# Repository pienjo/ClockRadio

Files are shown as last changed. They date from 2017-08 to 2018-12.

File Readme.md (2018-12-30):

This is just a simple alarm clock.

How to use
==========

## Main display

A short press on the mode button rotates between the following modes:

  * Time. The first 2 columns of the LED display are used for a Day-of-week indicator; monday is at the first row.
  * Date
  * Alarm 1.  
  * Alarm 2. 
  * One-time alarm

A long press on the mode button will edit whatever is being displayed (time,
alarm 1, alarm 2, or one-time alarm). Performing a long press while the
date is being shown will edit the time drift compensation. The display will
return to ''Time'' when no buttons are pressed.

## Display brightness

The display has separate brightness settings for day and night. Transition 
from day to night occurs roughly around sunrise (Assuming a northern 
lattitude of aroudn 51 degrees). 

Brightness can be changed using the ''increase'' and ''decrease'' buttons while the 
display is showing the time.

## Daylight saving time

The clock will automatically apply daylight saving time, based on the current (2019) 
EU rules (which are bound to change again, oh well)

## Editing

A short press on the mode button will advance to the next digit/number. Use 
the increment/decrement buttons to change digits/numbers. A long press
on the mode button will abort the edit.

## Radio

Pressing the on/off button will toggle the radio. When the radio is active,
the "Time" page will show the tuned frequency instead. When the radio is on,
the "Increase" and "Decrease" can be used for tuning. A short press on either
button will do a manual tune, a long press will perform an automatic seek for
the next channel.

To change the volume of the radio, hold down the on/off button and use the
increase/decrease buttons for volume control.

## Alarm

There are 2 regular alarms. They can sound on weekdays, on weekends, or both. 
They can be edited by doing a long-press on the mode button while the relevant
alarm is being displayed.

To disable or enable an alarm, press the ''on/off'' button while the alarm is
being displayed. Press the ''increment'' button to silence only the upcoming
invocation of the alarm. I added this because I often wake up before the
alarm is set to sound; in these cases I want to disable the alarm for today, 
but it should still arm itself for tomorrow without me having to remember
doing so...

Alarms can either turn on the radio, or turn on the beeper. While an alarm is
active, any button can be used to disable the alarm (the regular function of
the buttons is disabled while an alarm is active). When an alarm is scheduled
to go off while the previous alarm is still active, the first alarm is 
automatically silenced. (for example: my first alarm turns on the radio at
6:55 so I can listen to the news. If I'm not out of bed by 7:10, the second
alarm will sound the beeper).

Alarms will automatically be disabled after a certain timeout (1 hour for
radio alarms, 4 minutes for beeper alarms).

There is also a one-time alarm, for those times where you need to wakeup
at a non-standard hour. It behaves the same as the normal alarms, but doesn't
re-arm itself.

## sleep/nap

There is a sleep- or naptimer, sharing a single button. When the radio is
turned on while the sleep/nap button is pressed, the sleep function activates.
Press the button repeatedly to change the desired sleep interval. The radio
will turn off after this time.

If the radio was turned off when the sleep/nap button was pressed, the nap
function activates. It will sound the beeper alarm once the nap timer has 
expred. Press the sleep/nap button repeatedly to change the desired nap 
interval.

Both sleep and nap timers have a '':00'' interval - Selecting this interval
will disable the sleep/nap timer.

Hardware
========

Unfortunately, I lost the schematics for this clock. It was kind of cobbled
together at the spot. I'll include an overview, which should be enough to 
recreate a suitable schematic.

## Buttons

There are 5 switches, which pull down to GND:
 
  * **mode** (''BUTTON_1'', connected to PD0)
  * **on/off** (''BUTTON_2'', connected to PD1) 
  * **decrease** (''BUTTON_3'', connected to PD3)
  * **increase** (''BUTTON_4'', connected to PD4)
  * **sleep/nap** (''BUTTON_5'', connected to PD5)

There is **no** button connected to PD2 (ex0). Instead, it is connected to the
clock output of the DS1307. This will generate ''CLOCK_UPDATE'' events.

## Display 

The display consists of 4 MAX7219 modules from AliExpress. They came with an
8x8 LED matrix, and are connected in cascade (DOUT connected to DIN of the next
module. SCK is shared among all modules). 

They are configured over SPI, and use the hardware SPI module of the AVR:

  * MOSI (PB3 of the AVR) is connected to DIN of the first module.
  * SCK (PB5 of the AVR) is connected to CLK of the first module.
  * PB2 is connected to LOAD(/CS) of the first module.

I replaced the 8x8 matrix of the last module with a 4x7 segment display
plus some status LEDs on an adapter board. See the "schematics" in 
Hardware/display ) Note that the 4x7 segment that I happened to find in my
parts bin was common anode rather than common cathode!

## FM Radio

The clock uses an SI4702 radio module. **This module must be supplied with
3.3V**. I used an XC6206 low-dropout regulator.

The module is configured over I2C, using the hardware I2C module (SDA at PC4,
SCL at PC5). These need to be level-shifted because of difference in supply
voltage - I used a standard BSS138 based level shifter. See 
Hardware/levelshifter .

In addition, the reset line of the SI4702 module is connected to PC3. It 
doesn't need a level shifter; the AVR will only pull this low during the
power-up of the FM radio.

The outputs of the SI4702 need to be decoupled using a suitably large 
capacitor (I think I used a 10 uF electrolytic) because of different biasing.

## Beeper 

PC1 is used to generate a crude beeper. It is connected to the input of the
audio amplifier, using a potentiometer (for volume control) and a small
decoupling capacitor.

## Audio amplifier

I used a cheap amplifier module from AliExpress (LM386-based), connected to
4 small (29mm) speakers, .25W @ 8 Ohm, connected in two parallel chains of
2 (for a total impedance of 8 Ohm).

Since this amplifier turned out to be rather noisy, I added a PNP transistor
to its supply line, so it can be turned off if the radio and beeper are 
quiet. This transistor is controlled by PC2.

Building
========

You need to have the following installed:

  * A recent version of gcc-avr 
  * A recent version of avr-libc
  * avrdude for programming. The TX and RX lines are in use, so it's
    probably best to use an ISP programmer.
  * lua (5.1 or 5.2) to generate the bitmap- and font code.

To run the unittests in tests, you'll also need simavr plus its headers.

Case
====

I posted the case I made for this alarm clock to Thingiverse, see 

https://www.thingiverse.com/thing:3313125

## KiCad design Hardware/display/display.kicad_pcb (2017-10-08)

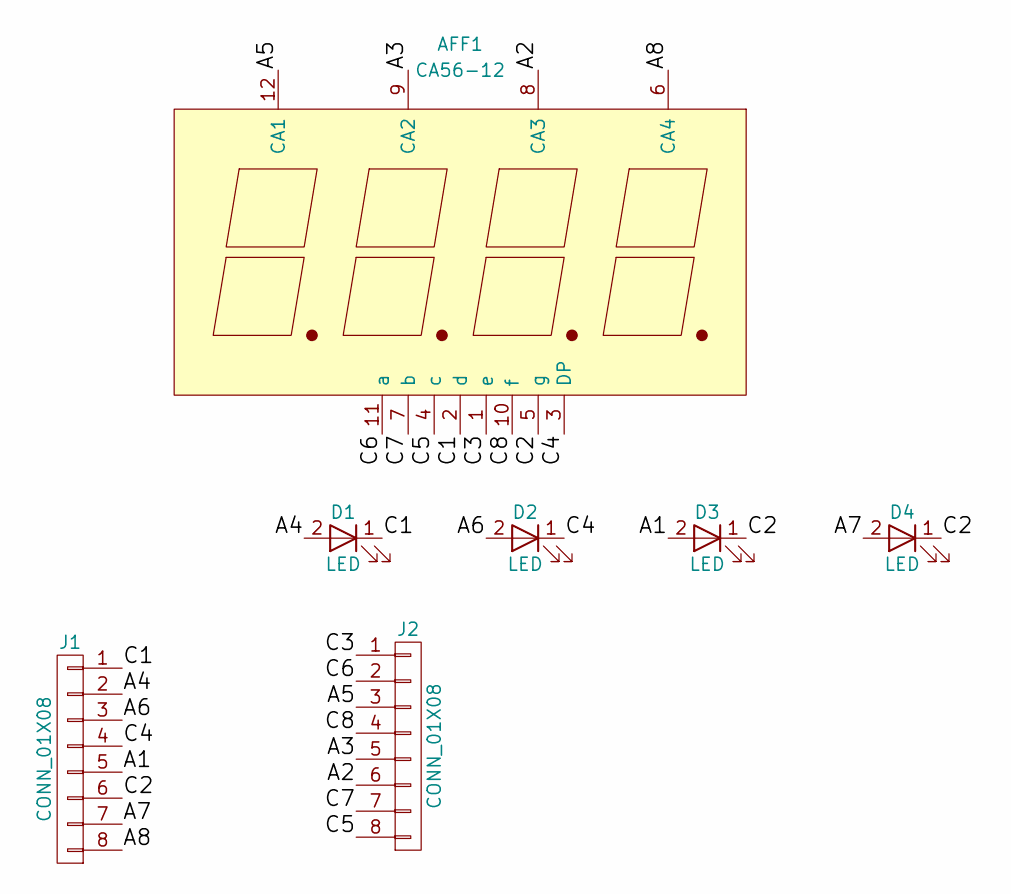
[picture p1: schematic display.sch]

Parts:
AFF1: CA56-12; SMA413064
D1, D2, D3, D4: LED; LED_D5.0mm
J1, J2: CONN_01X08; Pin_Header_Straight_1x08_Pitch2.54mm

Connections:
/A1: D3.2 (A), J1.5
/A2: AFF1.8 (CA3), J2.6
/A3: AFF1.9 (CA2), J2.5
/A4: D1.2 (A), J1.2
/A5: AFF1.12 (CA1), J2.3
/A6: D2.2 (A), J1.3
/A7: D4.2 (A), J1.7
/A8: AFF1.6 (CA4), J1.8
/C1: AFF1.2 (d), D1.1 (K), J1.1
/C2: AFF1.5 (g), D3.1 (K), D4.1 (K), J1.6
/C3: AFF1.1 (e), J2.1
/C4: AFF1.3 (DP), D2.1 (K), J1.4
/C5: AFF1.4 (c), J2.8
/C6: AFF1.11 (a), J2.2
/C7: AFF1.7 (b), J2.7
/C8: AFF1.10 (f), J2.4

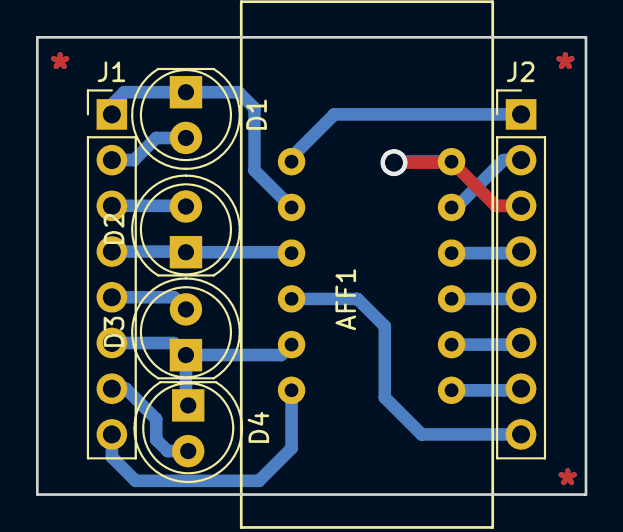
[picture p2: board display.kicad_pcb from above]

Board: 2 copper layers, 30.5 x 25.4 mm, 7 parts (0 on the bottom side), 16 nets.

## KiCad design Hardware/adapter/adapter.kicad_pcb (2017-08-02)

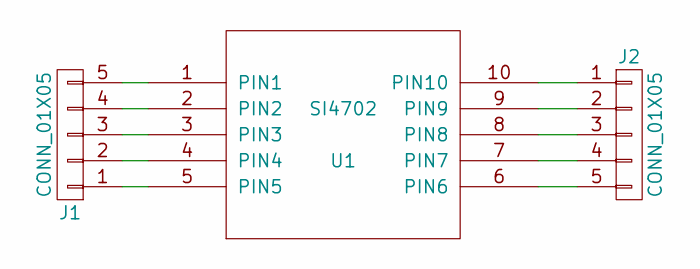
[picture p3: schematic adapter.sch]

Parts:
J1, J2: CONN_01X05; Pin_Header_Straight_1x05_Pitch2.54mm
U1: SI4702; mvb_SI4702

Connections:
unnamed: J1.1, U1.5 (PIN5)
unnamed: J1.2, U1.4 (PIN4)
unnamed: J1.3, U1.3 (PIN3)
unnamed: J1.4, U1.2 (PIN2)
unnamed: J1.5, U1.1 (PIN1)
unnamed: J2.1, U1.10 (PIN10)
unnamed: J2.2, U1.9 (PIN9)
unnamed: J2.3, U1.8 (PIN8)
unnamed: J2.4, U1.7 (PIN7)
unnamed: J2.5, U1.6 (PIN6)

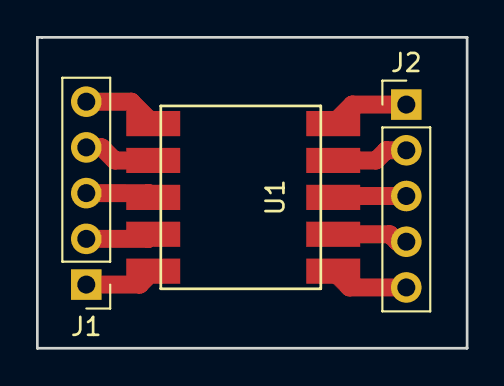
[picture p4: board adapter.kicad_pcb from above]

Board: 2 copper layers, 23.9 x 17.3 mm, 3 parts (0 on the bottom side), 10 nets.

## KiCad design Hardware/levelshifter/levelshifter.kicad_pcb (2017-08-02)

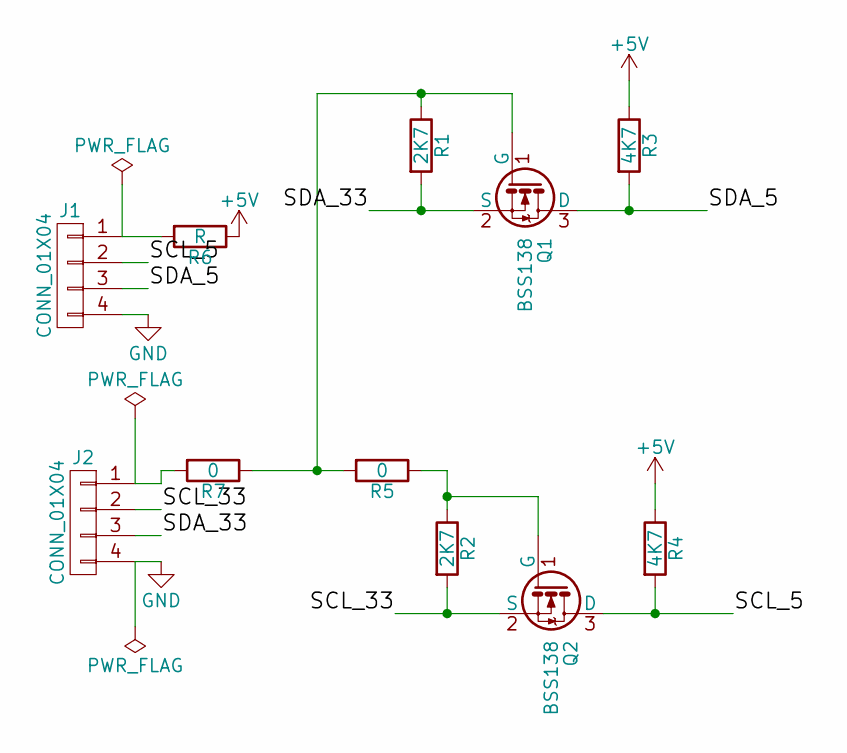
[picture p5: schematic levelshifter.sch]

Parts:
J1, J2: CONN_01X04; Pin_Header_Straight_1x04_Pitch2.54mm
Q1, Q2: BSS138; SOT-23_Handsoldering
R1, R2: 2K7; R_0603_HandSoldering
R3, R4: 4K7; R_0603_HandSoldering
R5: 0; R_Axial_DIN0204_L3.6mm_D1.6mm_P5.08mm_Horizontal
R6: R; R_Axial_DIN0204_L3.6mm_D1.6mm_P5.08mm_Horizontal
R7: 0; R_Axial_DIN0204_L3.6mm_D1.6mm_P7.62mm_Horizontal

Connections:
+5V: R3.1, R4.1, R6.1
/SCL_5: J1.2, Q2.3 (D), R4.2
/SCL_33: J2.2, Q2.2 (S), R2.2
/SDA_5: J1.3, Q1.3 (D), R3.2
/SDA_33: J2.3, Q1.2 (S), R1.2
GND: J1.4, J2.4
unnamed: J1.1, R6.2
unnamed: J2.1, R7.2
unnamed: Q1.1 (G), R1.1, R5.2, R7.1
unnamed: Q2.1 (G), R2.1, R5.1

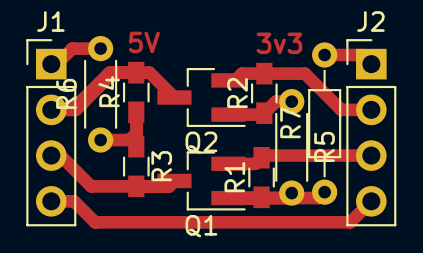
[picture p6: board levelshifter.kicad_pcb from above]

Board: 2 copper layers, 11 parts (0 on the bottom side), 10 nets.

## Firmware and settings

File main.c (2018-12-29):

/*
Copyright 2018, Martijn van Buul <martijn.van.buul@gmail.com>

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
THE SOFTWARE IS PROVIDED "AS IS" AND THE AUTHOR DISCLAIMS ALL WARRANTIES WITH
REGARD TO THIS SOFTWARE INCLUDING ALL IMPLIED WARRANTIES OF MERCHANTABILITY AND
FITNESS. IN NO EVENT SHALL THE AUTHOR BE LIABLE FOR ANY SPECIAL, DIRECT,
INDIRECT, OR CONSEQUENTIAL DAMAGES OR ANY DAMAGES WHATSOEVER RESULTING FROM
LOSS OF USE, DATA OR PROFITS, WHETHER IN AN ACTION OF CONTRACT, NEGLIGENCE OR
OTHER TORTIOUS ACTION, ARISING OUT OF OR IN CONNECTION WITH THE USE OR
PERFORMANCE OF THIS SOFTWARE.
*/
#include <avr/io.h>
#include <util/delay.h>
#include "Renderer.h"
#include "Panels.h"
#include "DateTime.h"
#include "events.h"
#include "longpress.h"
#include "DS1307.h"
#include "SI4702.h"
#include "settings.h"
#include "Timefuncs.h"
#include "BCDFuncs.h"

#include "i2c.h"

#include <avr/interrupt.h>
#include <avr/sleep.h>
#include <avr/wdt.h>
#include <util/atomic.h>

struct DateTime TheDateTime;
struct DateTime ThePreviousDateTime;

uint8_t TheSleepTime = 0;
uint8_t TheNapTime = 0;


#define BEEP_MARK             3
#define BEEP_SPACE           4
#define BEEP_COUNT           4
#define BEEP_ON_PERIOD       (BEEP_COUNT * (BEEP_MARK + BEEP_SPACE))
#define BEEP_PAUSE             BEEP_ON_PERIOD
#define BEEP_TOTALPERIOD     (BEEP_PAUSE + BEEP_ON_PERIOD)

#define SHOW_ALARM_TIMEOUT   15
#define TIME_ADJUST_TIMEOUT 15

#define ALARM_BEEP_TIMEOUT   4
#define ALARM_RADIO_TIMEOUT  60
#define INITIAL_SLEEPTIME    15
#define INITIAL_NAPTIME      INITIAL_SLEEPTIME

uint8_t beepState = 0;

_Bool radioIsOn = 0;
_Bool beepIsOn = 0;

enum clockMode
{
  modeShowTime,
  modeShowDate,
  modeShowRadio,
  modeShowRadio_Volume,
  modeShowAlarm1,
  modeShowAlarm2,
  modeShowOnetimeAlarm,
  modeAlarmFiring_beep,
  modeAlarmFiring_radio,
  modeAdjustYearTens,
  modeAdjustYearOnes,
  modeAdjustMonth,
  modeAdjustDayTens,
  modeAdjustDayOnes,
  modeAdjustHoursTens,
  modeAdjustHoursOnes,
  modeAdjustMinsTens,
  modeAdjustMinsOnes,
  modeAdjustHoursTens_Alarm,
  modeAdjustHoursOnes_Alarm,
  modeAdjustMinsTens_Alarm,
  modeAdjustMinsOnes_Alarm,
  modeAdjustDays_Alarm,
  modeAdjustType_Alarm,
  modeAdjustSleep,
  modeAdjustNap,
  modeAdjustTimeAdjust
} ;

volatile uint16_t event ;

uint8_t timer2_scaler = 2;

ISR (TIMER2_OVF_vect)
{
  // Crude button debouncer
  static uint8_t buttonDebounce[4] = { 0 };

  // First 3 array members are the debounce queue
  // Last array member is the reported button state
  
  // Add new data
  buttonDebounce[timer2_scaler] = PIND;
  
  // Handle beeping here, so timing is strict
  if (beepIsOn)
  {
    beepState = beepState + 1;
    
    if (beepState >= BEEP_TOTALPERIOD)
      beepState = 0;
    
    if (beepState < BEEP_ON_PERIOD)
    {
      uint8_t remainder = beepState;
      while(remainder >= (BEEP_MARK + BEEP_SPACE))
        remainder -= BEEP_MARK + BEEP_SPACE;
        
      if (remainder == 0)
      {
        // Turn on beeper
        TCCR0B = _BV(CS01) | _BV(CS00);
      }
      else if (remainder == BEEP_MARK)
      {
        // Turn off beeper
        TCCR0B = 0;
        PORTC &= ~(_BV(PORTC1));
      }
    }
  }
  
  uint8_t buttonsToReport = ~((buttonDebounce[0] ^ buttonDebounce[1]) | (buttonDebounce[1] ^ buttonDebounce[2]));
  // Now holds all buttons whose state has been stable over the last 3 scans (all values equal)

  // Only report buttons that haven't been reported yet.
  buttonsToReport &= (buttonDebounce[timer2_scaler] ^ buttonDebounce[3]);
 
  if (buttonsToReport)
  {
    // Mark as handled
    buttonDebounce[3] =( buttonDebounce[3] & (~buttonsToReport) ) | (buttonsToReport & buttonDebounce[timer2_scaler]);
  
    uint8_t pressedButtons = buttonsToReport & ~(buttonDebounce[timer2_scaler]);
    uint8_t releasedButtons = buttonsToReport & (buttonDebounce[timer2_scaler]);
    
    // Report
    event |= (uint16_t) pressedButtons | ((uint16_t)releasedButtons << 8);
  }

  if (timer2_scaler == 0)
  {
    event |= CLOCK_TICK; // results in ~48 ms per call
    timer2_scaler = 2;
  }
  else
  {
    timer2_scaler--;
  }
}

ISR (TIMER0_COMPA_vect)
{
  PINC = _BV(PORTC1); // Toggle output
}

static inline _Bool IsPastAlarmTime(const struct AlarmSetting *alarm, const struct DateTime *timestamp)
{
  return (timestamp->hour > alarm->hour) || (timestamp->hour == alarm->hour && timestamp->min >= alarm->min);
}

enum enumAlarmScheduleState {
  NOT_SCHEDULED = LED_OFF,          // Alarm is not scheduled for the next 24 hours
  SCHEDULED = LED_ON,                 // Alarm is scheduled
  SUSPENDED = LED_BLINK_SHORT,      // Alarm would've been scheduled, but the next invocation is suspended
};

enum enumAlarmScheduleState IsAlarmScheduled(struct AlarmSetting *alarm)
{
  if ((alarm->flags & ALARM_ACTIVE) == 0)
    return NOT_SCHEDULED;
  
  uint8_t dayBits = 0xff; // bit 0 = monday, bit 1 = tuesday ... bit 7 is monday again, to handle wraparound.
  
  switch (alarm->flags & ALARM_DAY_BITS)
  {
    case ALARM_DAY_WEEK:
      dayBits = 0x9f; // Trigger on mon-fri
      break;
    case ALARM_DAY_WEEKEND:
      dayBits = 0x60; // Trigger on sat-sun
  }
  
  // See if next alarm time is today or tomorrow.
  uint8_t nextAlarmDay; // 0-based
  
  if (IsPastAlarmTime(alarm, &TheDateTime))
  {
    // Alarm will trigger tomorrow.
    nextAlarmDay = TheDateTime.wday;
  }
  else
  {
    // Alarm will trigger today
    nextAlarmDay = TheDateTime.wday - 1; // 0-6
  }
    
  // Check if day matches
  if (! ( dayBits & (1 << nextAlarmDay)))
    return NOT_SCHEDULED;
    
  if ((alarm->flags & ALARM_SUSPENDED) == 0)
    return SCHEDULED;
  else
    return SUSPENDED;
}

void BeepOff()
{
  TCCR0B = 0; // Stop timer
  beepIsOn = 0;
  
  // Force beeper output low
  PORTC &= ~ _BV(PORTC1);
  
  // Amplifier control is active low
  PORTC = PORTC | _BV(PORTC2); 
}

void RadioOff()
{
  // Amplifier control is active low
  PORTC = PORTC | _BV(PORTC2);
  
  SI4702_PowerOff();
  radioIsOn = 0;
  TheSleepTime = 0;
}

void BeepOn()
{
  if (radioIsOn)
  {
    RadioOff();
  }
  
  beepIsOn = 1;
  beepState = BEEP_ON_PERIOD;

  // Amplifier control is active low
  PORTC = PORTC & ~( _BV(PORTC2)); 
}

_Bool RadioOn()
{
  if (radioIsOn)
    return 1; // Already on.
    
  if (beepIsOn)
  {
    BeepOff();
  }
  
  if (!SI4702_PowerOn())
  {
    return 0; // Failed to start the radio
  }
  
  SI4702_SetFrequency(TheGlobalSettings.radio.frequency);
  SI4702_SetVolume(TheGlobalSettings.radio.volume);
  
  Poll_SI4702();
  // Amplifier control is active low
  
  PORTC = PORTC & ~( _BV(PORTC2)); 
  radioIsOn = 1;  
  return 1;
}

uint8_t alarm1Timeout = 0; // minutes
uint8_t alarm2Timeout = 0; // minutes
uint8_t onetimeAlarmTimeout = 0; // minutes
uint8_t napTimeout = 0; // minutes

enum enumAlarmScheduleState alarm1Scheduled = NOT_SCHEDULED, alarm2Scheduled = NOT_SCHEDULED, onetimeAlarmScheduled = NOT_SCHEDULED;

void SilenceAlarm(struct AlarmSetting *alarm)
{
  if (alarm->flags & ALARM_TYPE_RADIO)
  {
    RadioOff();
  }
  else
  {
    BeepOff();
  }
}
  
_Bool AlarmTriggered(struct AlarmSetting *alarm)
{
  if (IsPastAlarmTime(alarm, &ThePreviousDateTime))
    return 0; // already triggered

  if (!IsPastAlarmTime(alarm, &TheDateTime) && ThePreviousDateTime.hour <= TheDateTime.hour)
    return 0; // Alarm not yet triggered, and no roll-over

  if ((alarm->flags & ALARM_DAY_NEVER) == ALARM_DAY_NEVER)
  {
    // Turn off alarm on one-time alarms
    alarm->flags &= ~ALARM_ACTIVE;
  }
  
  return 1;
}

void HandleCycleTime(uint8_t *time)
{
  uint8_t remainder = *time % 15;
  
  *time += (15 - remainder);
  if (*time > 150)
    *time = 0;
}

struct deviceState
{
  uint8_t modeTimeout;
  int8_t  timeAdjustRemainder;
  _Bool   timeAdjustApplied;
  enum clockMode deviceMode;

} TheDeviceState;

void SilenceAlarms()
{
  if (alarm1Timeout)
  {
    alarm1Timeout--;
    if (!alarm1Timeout)
      SilenceAlarm(&TheGlobalSettings.alarm1);
  }
  
  if (alarm2Timeout)
  {
    alarm2Timeout--;
    if (!alarm2Timeout)
      SilenceAlarm(&TheGlobalSettings.alarm2);
  }
  
  if (onetimeAlarmTimeout)
  {
    onetimeAlarmTimeout--;
    if (!onetimeAlarmTimeout)
      SilenceAlarm(&TheGlobalSettings.onetime_alarm);
  }
  
  if (TheSleepTime && TheDeviceState.deviceMode != modeAdjustSleep)
  {
    TheSleepTime--;
    if (TheSleepTime == 0)
    {
      RadioOff();
      if (!TheDeviceState.modeTimeout)
        TheDeviceState.modeTimeout = 1;
    }
  }
  
  if (napTimeout)
  {
    napTimeout--;
    if (!napTimeout)
    {
      BeepOff();
    }
  }
}

enum clockMode ActivateAlarms()
{
  enum clockMode newDeviceMode = TheDeviceState.deviceMode;

  if (TheNapTime && TheDeviceState.deviceMode != modeAdjustNap)
  {
    TheNapTime--;
    if (TheNapTime == 0)
    {
      BeepOn();
      alarm1Timeout = 0;
      alarm2Timeout = 0;
      TheSleepTime = 0;
      napTimeout = ALARM_BEEP_TIMEOUT;
      newDeviceMode = modeAlarmFiring_beep;
    }
  }
  
  // See if alarms must fire.
  
  switch(alarm1Scheduled)
  {
    case NOT_SCHEDULED:
      break;
    case SCHEDULED:
      if (AlarmTriggered(&TheGlobalSettings.alarm1))
      {
        napTimeout = 0;
        alarm2Timeout = 0;
        onetimeAlarmTimeout = 0;
        TheSleepTime = 0;
        
        if ((TheGlobalSettings.alarm1.flags & ALARM_TYPE_RADIO) && RadioOn())
        {
          // Radio alarm, and radio could be started
          
          alarm1Timeout = ALARM_RADIO_TIMEOUT;
          newDeviceMode = modeAlarmFiring_radio;
        }
        else
        {
          // Beep alarm, or failed to start radio
          BeepOn();
          alarm1Timeout = ALARM_BEEP_TIMEOUT;
          newDeviceMode = modeAlarmFiring_beep;
        }
      }
      break;
    case SUSPENDED:
      if (AlarmTriggered(&TheGlobalSettings.alarm1))
      {
        // Remove suspend state
        TheGlobalSettings.alarm1.flags &= ~(ALARM_SUSPENDED);
      }
      break;
  }
  
  switch(alarm2Scheduled)
  {
    case NOT_SCHEDULED:
      break;
    case SCHEDULED:
      if (AlarmTriggered(&TheGlobalSettings.alarm2))
      {
        napTimeout = 0;
        alarm1Timeout = 0;
        onetimeAlarmTimeout = 0;
        TheSleepTime = 0;
        
        if ((TheGlobalSettings.alarm2.flags & ALARM_TYPE_RADIO) && RadioOn())
        {
          // Radio alarm, and radio could be started
          
          alarm2Timeout = ALARM_RADIO_TIMEOUT;
          newDeviceMode = modeAlarmFiring_radio;
        }
        else
        {
          // Beep alarm, or failed to start radio
          BeepOn();
          alarm2Timeout = ALARM_BEEP_TIMEOUT;
          newDeviceMode = modeAlarmFiring_beep;
        }
      }
      break;
    case SUSPENDED:
      if (AlarmTriggered(&TheGlobalSettings.alarm2))
      {
        // Remove suspend state
        TheGlobalSettings.alarm2.flags &= ~(ALARM_SUSPENDED);
      }
      break;
  }
  
  if(onetimeAlarmScheduled == SCHEDULED && AlarmTriggered(&TheGlobalSettings.onetime_alarm))
  {
    napTimeout = 0;
    alarm1Timeout = 0;
    alarm2Timeout = 0;
    TheSleepTime = 0;
    
    if ((TheGlobalSettings.onetime_alarm.flags & ALARM_TYPE_RADIO) && RadioOn())
    {
      // Radio alarm, and radio could be started
      
      onetimeAlarmTimeout = ALARM_RADIO_TIMEOUT;
      newDeviceMode = modeAlarmFiring_radio;
    }
    else
    {
      // Beep alarm, or failed to start radio
      BeepOn();
      onetimeAlarmTimeout = ALARM_BEEP_TIMEOUT;
      newDeviceMode = modeAlarmFiring_beep;
    }
  }

  return newDeviceMode;
}

void ApplyTimeAdjust()
{
  int8_t adjust = 0;

  TheDeviceState.timeAdjustRemainder += TheGlobalSettings.time_adjust;

  if (TheDeviceState.timeAdjustRemainder >= 10)
  {
    while(TheDeviceState.timeAdjustRemainder >= 10)
    {
      ++adjust;
      TheDeviceState.timeAdjustRemainder -= 10;
    }

    if (adjust >= 10)
      adjust += 6;

    TheDateTime.sec = BCDAdd(TheDateTime.sec, adjust);
    Write_DS1307_DateTime();
  }
  else if (TheDeviceState.timeAdjustRemainder <= -10)
  {
    while(TheDeviceState.timeAdjustRemainder <= -10)
    {
      ++adjust;
      TheDeviceState.timeAdjustRemainder += 10;
    }

    if (adjust >= 10)
      adjust += 6;

    TheDateTime.sec = BCDSub(TheDateTime.sec, adjust);
    Write_DS1307_DateTime();
  }
}

int main(void)
{
  // Setup watchdog
  wdt_enable(WDTO_4S);
  
  // Enable output on PORT C2 (amplifier control) and C1 (beeper)
  DDRC |= _BV(PORTC2) | _BV(PORTC1);
  // Amplifier control is active low
  PORTC = PORTC | _BV(PORTC2);
  
  wdt_reset();
  
  InitializePanels(4);
  
  Init_I2C();
  Init_DS1307();
  Init_SI4702();
  Renderer_Init();
  
  // Read radio defaults
  if (!ReadGlobalSettings())
  {
    // settings are lost, initialize
    TheGlobalSettings.radio.frequency = 875; // start of band
    TheGlobalSettings.radio.volume = 26;
    
    TheGlobalSettings.alarm1.flags = ALARM_TYPE_RADIO | ALARM_DAY_WEEK; // Disabled, Repeat on weekdays, radio
    TheGlobalSettings.alarm1.hour = 7;
    TheGlobalSettings.alarm1.min = 0;
    
    TheGlobalSettings.alarm2.flags = ALARM_DAY_WEEKEND; // Disabled, repeat on weekend, beeper
    TheGlobalSettings.alarm2.hour = 9;
    TheGlobalSettings.alarm2.min = 0x15; 
    
    TheGlobalSettings.onetime_alarm.flags = ALARM_DAY_NEVER; // Never repeat, disabled
    TheGlobalSettings.onetime_alarm.hour = 6;
    TheGlobalSettings.onetime_alarm.min = 0x45;
    
    TheGlobalSettings.brightness = 13;
    TheGlobalSettings.brightness_night = 3;
    TheGlobalSettings.time_adjust = 0; 
    WriteGlobalSettings();
  }

  SetBrightness(GetActiveBrightness(&TheDateTime));
  
  // Set port D to input, enable pull-up on portD except for PortD2 (ext0)

  DDRD = 0;
  PORTD = ~(_BV(PORTD2));

  TIMSK2 = _BV(TOIE2); // Enable overflow interrupt, will trigger every 16 ms
  
  // Setup timer 2: /1024 prescaler, 
  TCCR2B = _BV(CS22) | _BV(CS21) | _BV(CS20); 

  // Setup beeper timer.
  TCCR0A = _BV(WGM01); // CTC mode.  
  // Target frequency: 1600 Hz, two interrupts per cycle, or 5000 clock ticks.
  OCR0A = 78; // To be used with a /64 clock scaler
  TIMSK0 = _BV(OCIE0A); // Enable output match interrupt
  
  uint8_t secMode = SECONDARY_MODE_SEC;
  uint8_t mainMode = MAIN_MODE_TIME;

  TheDeviceState.deviceMode = modeShowTime;
  TheDeviceState.modeTimeout = 0;
  TheDeviceState.timeAdjustApplied = true;
  TheDeviceState.timeAdjustRemainder = false;

  uint8_t *editDigit = 0;
  uint8_t editMode = 0;
  uint8_t editMaxValue = 0x99;
  
  uint8_t writeSettingTimeout = 0; // seconds
  
  _Bool timePollAllowed = 1;
  
  sei(); // Enable interrupts. This will immediately trigger a port change interrupt; sink these events.
  
  struct AlarmSetting alarmBeingModified;
  enum clockMode alarmAdjustReturnMode = 0;
  
  uint16_t clockEvents = 0;
  uint16_t buttonEvents = 0;
  struct longPressResult longPressEvent;
  
  longPressEvent.shortPress = 0;
  longPressEvent.longPress = 0;
  longPressEvent.repPress = 0;
  
  while (1)
  {
    
    wdt_reset();
  
    _Bool updateScreen = 0;
    uint16_t acceptedEvents = 0;
    ATOMIC_BLOCK(ATOMIC_FORCEON)
    {
      acceptedEvents = event;
      event = 0;
    }
    
    GetLongPress(acceptedEvents, &longPressEvent);
    clockEvents = (acceptedEvents & (CLOCK_UPDATE | CLOCK_TICK)) ;
    buttonEvents |= (acceptedEvents & ~(CLOCK_UPDATE | CLOCK_TICK));
      
    enum clockMode newDeviceMode = TheDeviceState.deviceMode;

    if (clockEvents & CLOCK_UPDATE)
    {
      if (writeSettingTimeout)
      {
        --writeSettingTimeout;
        if (writeSettingTimeout == 0)
        {
          WriteGlobalSettings();
        }
      }
      
      if (TheDeviceState.modeTimeout && --TheDeviceState.modeTimeout == 0)
      {
         newDeviceMode = (radioIsOn?modeShowRadio : modeShowTime) ;
      }
    
      if (timePollAllowed)
      {
        Read_DS1307_DateTime();
        
        updateScreen = 1;

        if (!TheDeviceState.timeAdjustApplied && TheDateTime.sec >= 30)
        {
          ApplyTimeAdjust();
          TheDeviceState.timeAdjustApplied = true;
        }        

        if (ThePreviousDateTime.sec > TheDateTime.sec)
        {
          // Second rollover.

          if (ThePreviousDateTime.min > TheDateTime.min && TheDateTime.hour == 0)
          {
            // Day rollover. Check for time drift at the 30 second mark.  
            TheDeviceState.timeAdjustApplied = false;
          }

          // See if alarms must timeout
          SilenceAlarms();

          newDeviceMode = ActivateAlarms();
          
          SetBrightness(GetActiveBrightness(&TheDateTime));
        }
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

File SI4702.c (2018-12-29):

/*
Copyright 2018, Martijn van Buul <martijn.van.buul@gmail.com>

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
THE SOFTWARE IS PROVIDED "AS IS" AND THE AUTHOR DISCLAIMS ALL WARRANTIES WITH
REGARD TO THIS SOFTWARE INCLUDING ALL IMPLIED WARRANTIES OF MERCHANTABILITY AND
FITNESS. IN NO EVENT SHALL THE AUTHOR BE LIABLE FOR ANY SPECIAL, DIRECT,
INDIRECT, OR CONSEQUENTIAL DAMAGES OR ANY DAMAGES WHATSOEVER RESULTING FROM
LOSS OF USE, DATA OR PROFITS, WHETHER IN AN ACTION OF CONTRACT, NEGLIGENCE OR
OTHER TORTIOUS ACTION, ARISING OUT OF OR IN CONNECTION WITH THE USE OR
PERFORMANCE OF THIS SOFTWARE.
*/
#include "i2c.h"
#include <avr/io.h>
#include "SI4702.h"
#include <stdbool.h>
#include <util/delay.h>

#define SI4702_ADDR 0x20
#define SI4702_RECOVERY_ATTEMPTS 3

// The SI4702 has bigendian registers, the AVR is little endian. 
// Work around this by not addressing the registers as 16 bits - it's not really that useful
// to access them as 16 bits anyway - only the 9-bit tuning registers benefit from 16-bit
// access, but that's easily fixed

// The SI4702 has a very weird I2C interface. For some bizarre reason, Read-out starts at address 
// 0x0A, then auto-increment to 0x0F, and then wraps around to address 0. Write-out starts at 
// register adddress 2, and since address 8 and 9 may not be written to is restricted to registers
// 2 through 7. 

// Work around the read-out wraparound by re-arranging the registers so that register 0X0a is relocated
// to 0x00/0x01, 0x0f is relocated to 0x0a/0x0b, the wrapped-around address '0' moves to 0x0c/0x0d, 
// register 2 (write-out start address) sits at 0x10/0x11 and register 9 sits at 0x1E/0X1F

// Registers cannot be accessed directly, so there's no reason to keep the weird original layout. 
#define RELOCATED_REGISTER_2 POWERCONFIG_H

uint8_t SI4702_regs[32]; 

// Register definitions

// REGISTER A
#define STATUS_RSSI_H 0x00
  #define RDSR 0x80 // RDS ready
  #define STC  0x40 // Seek/tune complete
  #define SBFL 0x20 // Seek Fail / Band Limit
  #define AFCRL 0x10 // AFC fail
  #define RDSS 0x08 // RDS synchronized
  
  #define BLERA(x) ((x & 0x06) >> 1) // RDS block A errors
  #define ST 0x01   // Stereo

#define STATUS_RSSI_L 0x01
  // [0:7] : RSSI (REceived Signal Strength Indicator)

// REGISTER B
#define READ_CHANNEL_H 0x02
  #define BLERB(x) ((x & 0xC0) >> 6) // RDS Block B errors
  #define BLERC(x) ((x & 0x30) >> 4) // RDS Block C errors
  #define BLERD(x) ((x & 0xc0) >> 2) // RDS block D erros
  #define READ_CHANNEL_H_BITS 0x3 // ReadChannel[8:9]

#define READ_CHANNEL_L 0x03
  // ReadChannel[7:0]

// REGISTER C
#define RDSA_H   0x04
#define RDSA_L   0x05

// REGISTER D
#define RDSB_H   0x06
#define RDSB_L   0x07

// REGISTER E
#define RDSC_H   0x08
#define RDSC_L   0x09

// REGISTER F
#define RDSD_H   0x0a
#define RDSD_L   0x0b

// REGISTER 0
#define DEVICEID_H     0x0c
  #define PN_BITS      0xF0 // Part number mask
  #define MFGID_H_BITS 0x0F // Bits 8-11 of manufacturer ID.

#define DEVICEID_L     0x0d
  #define MFGID_L_BITS 0xff // bits 0-7 of manufacturer ID
  
// REGISTER 1
#define CHIPID_H       0x0e
  #define REV_BITS     0xFC // Revision (?) bits
  #define DEV_H_BITS   0x03
#define CHIPD_L	       0x0f
  #define DEV_L_BITS   0xC0
  #define FIRMWARE     0x3F
  
// REGISTER 2
#define POWERCONFIG_H  0x10

  #define DSMUTE  0x80 // Disable softmute
  #define DMUTE   0x40 // Disable mute
  #define MONO    0x20 // mono
  #define RDSM	  0x08 // RDS mode (not supported)
  #define SKMODE  0x04 // Seek mode: stop seeking at band end
  #define SEEKUP  0x02 // Seek up
  #define SEEK    0x01 // Start seeking

#define POWERCONFIG_L 0x11
  #define DISABLE 0x40 // Power up disable
  #define ENABLE  0x01 // Powerup enable

// REGISTER 3
#define CHANNEL_H 0x12
  #define TUNE	   0x80 // Start tuning.
  #define CHANNEL_H_BITS 0x03 // Channel[8:9]

#define CHANNEL_L 0x13
  // Channel[7:0]

// REGISTER 4
#define SYSCONFIG1_H 0x14
  #define RDSIEN  0x80 // RDS interrupt enable (not supported)
  #define STCIEN  0x40 // Seek/Tune interrupt enable (not supplied by breakout board)
  #define RDS     0x10 // RDS enable (not supported)
  #define DE      0x08 // De-emphasis. 0 for USA, 1 for rest of world
  #define AGCD    0x04 // Automatic Gain Control disable

#define SYSCONFIG1_L 0x15
  // Stereo/mono blend
  #define BLENDADJ_0 0x00 // +0 dB
  #define BLENDADJ_1 0x40 // +6 dB
  #define BLENDADJ_2 0x80 // -12 dB
  #define BLENDADJ_3 0xC0 // -6 dB
  #define BLENDADJ_BITS BLENDADJ_3

  // GPIO3 mode (not bonded out)
  #define GPIO3_HI_Z 0x00
  #define GPIO3_ST   0x10 // Stereo indicator
  #define GPIO3_LOW  0x20 // force low
  #define GPIO3_HIGH 0x30 // Force high
  #define GPIO3_BITS GPIO3_HIGH

  // GPIO2 mode (not bonded out)
  #define GPIO2_HI_Z 0x00
  #define GPIO2_INT  0x04 // Seek/Tune or RDS interrupt
  #define GPIO2_LOW  0x08 // force low
  #define GPIO2_HIGH 0x0C // Force high
  #define GPIO2_BITS GPIO2_HIGH

  // GPIO1 mode (not bonded out)
  #define GPIO1_HI_Z 0x00
  #define GPIO1_LOW  0x02 // force low
  #define GPIO1_HIGH 0x03 // Force high
  #define GPIO1_BITS GPIO1_HIGH

// REGISTER 5
#define SYSCONFIG2_H  0x16
  // bits 0:7 : seek threshold.
#define SYSCONFIG2_L  0x17
  #define BAND_US_EU 0x00 // 87.5 - 108MHz (US / Europe / Australia)
  #define BAND_JP_WD 0x40 // 76 - 108 (Japan wide band)
  #define BAND_JP    0x80 // 76 - 89 MHz (japan)
  #define BAND_BITS  0xC0
 
  #define SPACE_200KHZ 0x00 // 200 KHz spacing (US /Australia)
  #define SPACE_100KHZ 0x10 // 100 KHz spacing (Europe/Japan)
  #define SPACE_50KHZ  0x20 // 50 KHz spacing
  #define SPACE_BITS   0x30 
  // bits 3:0 : Volume.
  #define VOLUME_BITS  0x0F

// REGISTER 6
#define SYSCONFIG3_H  0x18
  #define SMUTER_FASTEST   0x00 // Softmute attack/recovery rate
  #define SMUTER_FAST      0x40
  #define SMUTER_SLOW      0x80
  #define SMUTER_SLOWEST   0xC0
  #define SMUTER_BITS SMUTER_SLOWEST

  #define SMUTEA_0	   0x00 // 16dB
  #define SMUTEA_1         0x10 // 14 dB
  #define SMUTEA_2         0x20 // 12 dB
  #define SMUTEA_3         0x30 // 10 dB
  #define SMUTEA_BITS	   SMUTEA_3
  
  #define VOLEXT 0x01      // extended volume rage (output attenuates by 30 dB)

#define SYSCONFIG3_L   0x19
  #define SKSNR(x)  (x << 4) // Seek SNR threshold (0 = most stops, 7 = fewest stops)
  #define SKSNR_BITS 0xf0
  #define SKCNT(x)  (x)
  #define SKCNT_BITS  0x0f


// REGISTER 7
#define TEST1_H 0x1a
  #define XOSCEN 0x80       // Crystal oscillator enable
  #define AHIZEN 0x40       // Audio High-Z enable

#define TEST1_L 0x1b
  // reserved

// REGISTER 8
#define TEST2_H 0x1c    
  // reserved
#define TEST2_L 0x1d    
  // reserved

// REGISTER 9
#define BOOTCONFIG_H 0x1e
  // reserved

#define BOOTCONFIG_L 0x1f
  // reserved

static inline _Bool Read_SI4702()
{
  return Read_I2C_Raw(SI4702_ADDR, 32, SI4702_regs);
}

static inline _Bool Write_SI4702()
{
  return Write_I2C_Raw(SI4702_ADDR, 12, SI4702_regs + RELOCATED_REGISTER_2); 
}
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

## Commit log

2017-03-25 It actually shows something
    * Created crude rendering engine
    * Fixed font
    [main.c]
2017-03-31 Don't use a frame buffer, just compose lines individually
2017-04-06 Migrate to target board - which turns out to have an ATMega 168p instead :(
2017-04-06 Extensive changes
    * Moved DS1307 code to separate .c file
    * Moved SPI initialisation there
    * Use a timer for the animation ticks
    * Configure the DS1307 to use a 1-sec timer, use that to wake up the cpu
    * Put CPU to sleep between updates
    * Add a 4th panel, featuring 4 7-segment displays.
    * Glue code to compensate for the "wrong" type of display
    * Started a SVG file featuring my "case".
    [7Segment.h, DS1307.c, Panels.c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]
2017-04-11 Started button handling
2017-08-02 Unfinished, but want to continue on shiny
    [adapter.kicad_pcb, adapter.sch, levelshifter.kicad_pcb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]
2017-08-07 Enable crude radio. Only tuning, no repeat, no seek. Remove special treatment of the clock signal - there's no need for an external EXT0 handler.. Correctly implement disabling of radio.
    [Renderer.h, SI4702.c, main.c]
2017-08-26 Add macros for LEDs.
2017-08-26 Add support for status LEDs. Add volume viewing
2017-09-03 PCB for display adapter
    [display.kicad_pcb, display.sch]
2017-09-03 Only pull down RESET line, don't pull it up. Prevents overloading the ESD diodes of the radio chip..
    [SI4702.c]
2017-09-04 Fixed column of leds
    [7Segment.h]
2017-09-04 Change setting storage: * Add 2 alarms * Implement CRC checking to detect lost data * Show the two alarms. * Use a timer to write settings.
2017-09-06 Allow editing of alarms. Problem: No flash mask for days.
    [main.c]
2017-09-07 Change rendering of alarm. Fixes setting of alarm
    [Renderer.h, main.c]
2017-10-01 Nap- and sleep timer
2017-10-01 Added 2 more LEDs
    [display.kicad_pcb, display.sch]
2017-10-08 Finalized 7-segment adapter board.
    [display.kicad_pcb]
2017-10-08 Use all 4 LEDs
2017-10-15 Add DST handling
    Known issue: DST switch not handled when clock is running on backup
    [DS1307.c, main.c]
2017-10-15 Apply DST change after power recovery.
    Untested.
2017-10-15 Re-try reset of SI4702 if it doesn't respond.
    [SI4702.c, i2c.c]
2017-10-15 Improve time setting
    * Keep updating the time when setting the date.
    * Keep updating the second register when setting the time.
    * Allow the second register to be reset
    * Don't write the second register when done setting time. This
    avoid resetting the second divider
    [DS1307.c, main.c]
2018-04-05 Revert "Improve time setting"
    This reverts commit 912c0d4aaa939b37706aa454e5420bd57b75260c.
    [DS1307.c, main.c]
2018-04-05 Revert "Apply DST change after power recovery."
    This reverts commit f36825cdc5ec0c8c8f84a6f0239469cbc25ce133.
    [main.c]
2018-04-05 Revert "Add DST handling"
    This reverts commit f66c807ea54dc31d3d43feee1b297fb95b94a05c.
    [DS1307.c, main.c]
2018-04-07 Separated BCD functions to separate file, add more tests.
    Fixed several newly discovered bugs in timefuncs :(
    [tests.c]
2018-04-07 Write tests for NormalizeHours + fix
    [tests.c]
2018-04-07 Add tests for IsDSTActive (No bugs, yay)
    [tests.c]
2018-04-07 Bugsquash
    Fix warnings from cppcheck.
    Fix alarm time checking
    [SI4702.c, main.c]
2018-04-07 Auto-switch brightness
2018-04-08 Only update screen when something actually changed. Reduces noise on the radio when tuned to a weak station
    [Renderer.h, main.c]
2018-04-10 Fix (?) I2C instability, rewrite SI4702 register layout
    [SI4702.c, i2c.c]
2018-04-15 Fix day-of-week rollover
    also fix tests
    [tests.c]
2018-04-15 Failing to ack I2C data is a failure
    [i2c.c]
2018-04-20 Always re-initialize SI4702 when powering it on
2018-04-20 Add support for inverted display
    [Renderer.h]
2018-04-20 Invert screen when radio alarm is firing, instead of blinking.
    [main.c]
2018-11-12 Fix display of time adjust, actually implement adjustment
    [main.c]
2018-11-13 Misc bugfix
    * Move edit handling to BCDFuncs, add unittests, fix bugs.
    * Fix time adjustment BCD bug
    * obliterate data segment size of tests.
    [main.c, tests.c]
2018-12-29 Remove dead case
